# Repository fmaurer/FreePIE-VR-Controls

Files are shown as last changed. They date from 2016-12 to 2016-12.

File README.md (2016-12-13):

# FreePIE-VR-Controls

Emulates HTC Vive Controllers with Arduino's, IMUs, and the Leap Motion sensor. Using the Leap Motion sensor for positional tracking of hands and orientation from an Arduino, HTC Vive controller data is spoofed by using FreePIE to generate Razer Hydra data. To simplify, the Arduino is flashed as a USB joystick and passes orientation data through the 16-bit joystick axis values, along with button presses.

https://youtu.be/kD7rpQKc5ew

Additional info, photos, and videos:
http://flrnmrr.com/2016/11/30/arduino-vive-controller-emulation

Requirements:

- Tracked VR headset (Oculus DK2)
- FreePIE     http://andersmalmgren.github.io/FreePIE/
- Leap Motion sensor, Orion installed     https://api.leapmotion.com/orion
- Steam VR Razer Hydra Driver     http://store.steampowered.com/app/491380/
- Sixsense SDK     http://sixense.com/windowssdkdownload
- "... copy the sixense_fake.dll (located in the root folder of your FreePIE installation) over the sixense.dll in the folder of the application you want use this plugin with. "
- 2 x USB joysticks (i.e. Arduino's simulating joystick HID devices)
- recommended: xbox 360 controller for testing

Arduino:

- Firmware is written for Arduino Pro Micro. Different Arduinos may use different pins
- copy the libraries into your Arduino folder (default is ~/Documents/Arduino/libraries)
- Some can be obtained through the library manager in the Arduino IDE

3D Printer files:

- very early version
- comes as multiple pieces that require to be fused together (e.g. handle and joystick mount)
- requires a lot of modification, I suggest ABS plastic as filament material. Hack your buttons into it, I used arcade buttons

How to Use:

- Run Steam VR
- Open FreePIE, run script
- To calibrate, point the Arduino's IMU/orientation sensor forward and press left-thumbstick down on the 360 controller (change line 163 "if ((xbox360[i].leftThumb) ):" for different key)

Support:

- Sixsense SDK has testing app under "Samples" folder of download
- The script assumes the Arduino-joysticks feeding the orientation data are index 0 and 1. Most problems can be addressed by change these indexes near Line 147: "joyLi" and "joyRi"
- Still having issues? Have you tried Right-click > "Run as Administrator"?
- If all else fails, test if you can make it work with just a 360 controller: http://www.mtbs3d.com/phpbb/viewtopic.php?f=139&t=19270

(More install help: http://www.mtbs3d.com/phpBB/viewtopic.php?f=139&t=19753 )

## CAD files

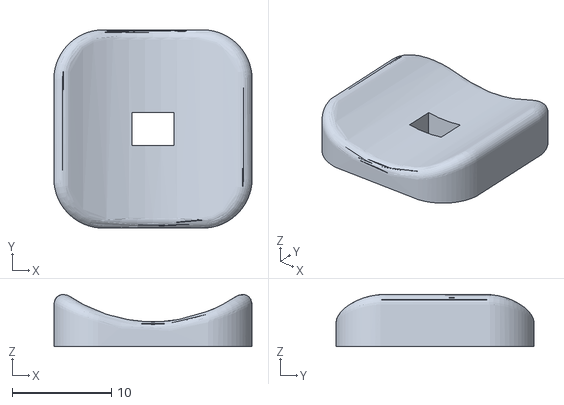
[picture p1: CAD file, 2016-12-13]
3D Printer Files/hand controller joystick shape.stl
20.0 x 20.0 x 5.26

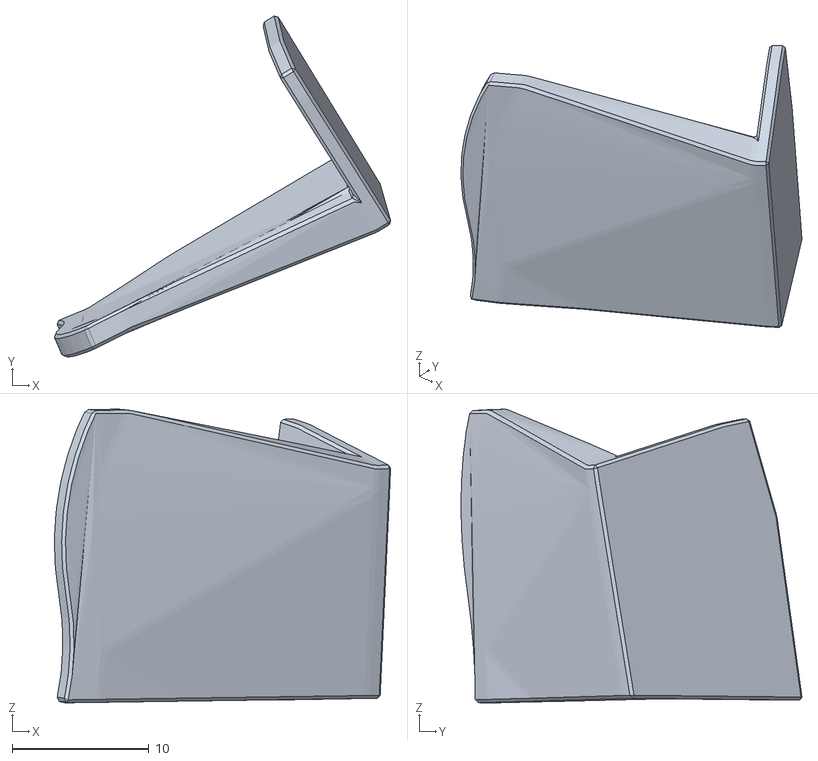
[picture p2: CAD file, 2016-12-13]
3D Printer Files/hand controller 7 lid.stl
24.5 x 24.9 x 21.4

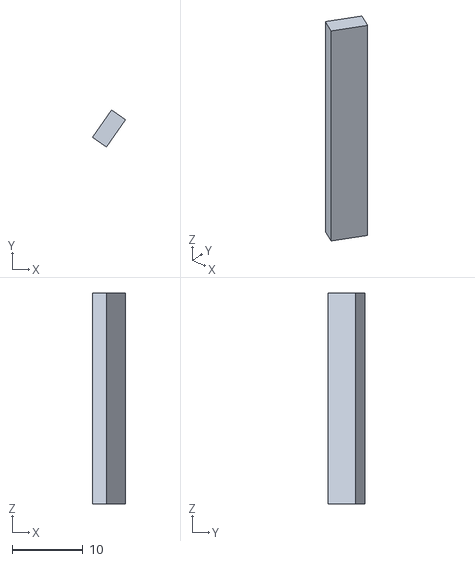
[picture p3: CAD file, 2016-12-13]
3D Printer Files/hand controller 7 joystick thumb centerPin fix 2 x2.stl
4.69 x 5.26 x 29.9

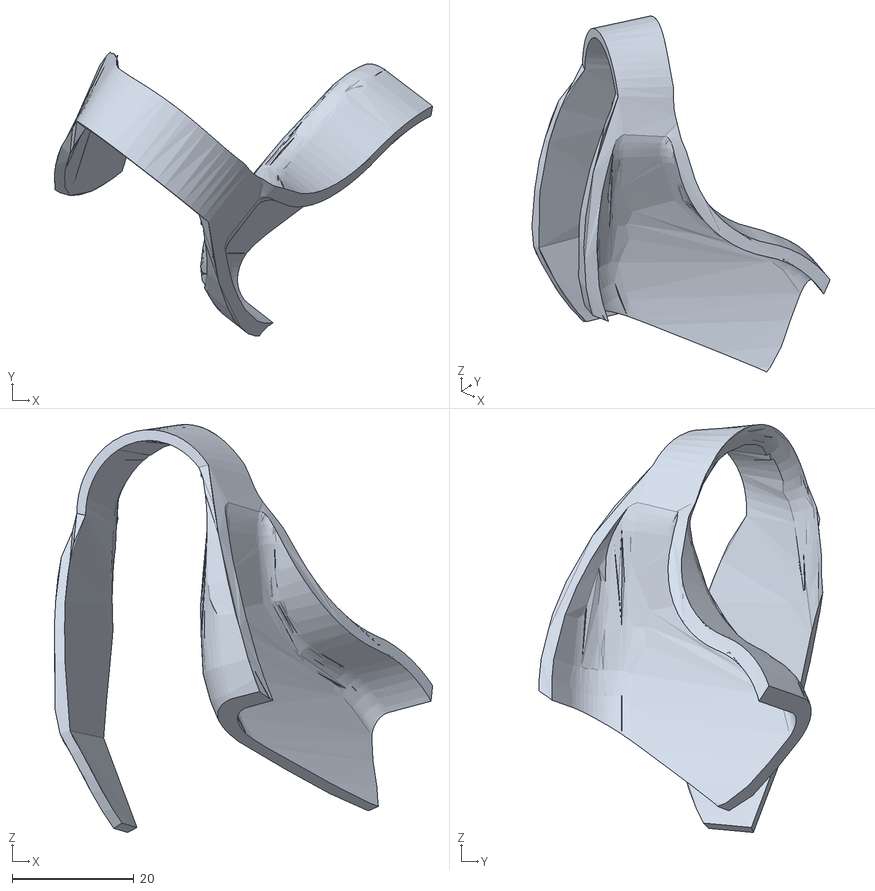
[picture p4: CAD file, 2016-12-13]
3D Printer Files/hand controller og base1.stl
62.1 x 46.5 x 66.9

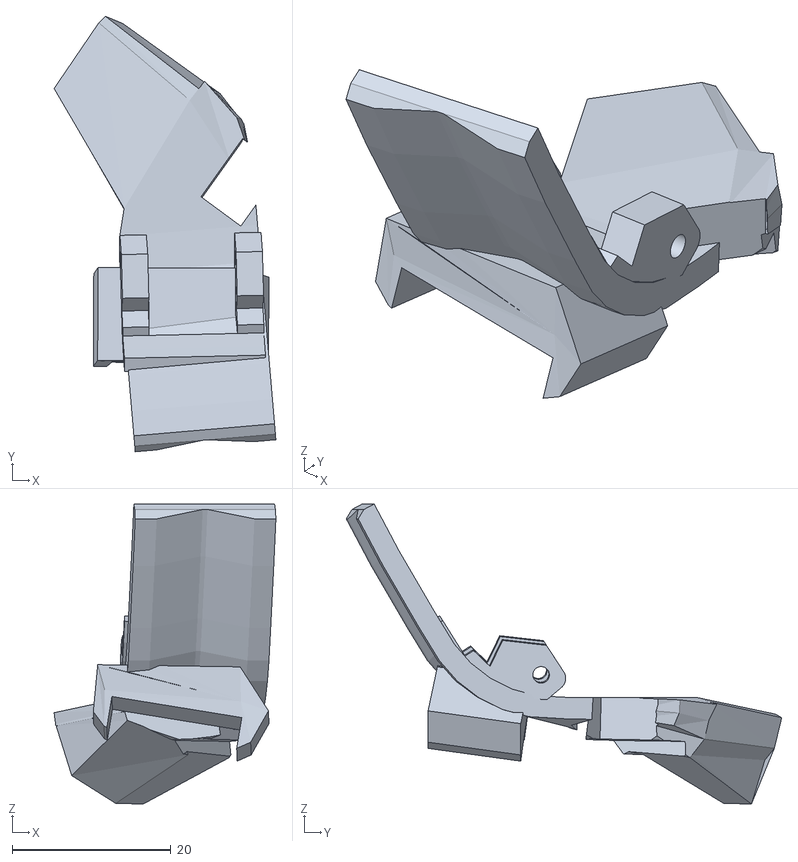
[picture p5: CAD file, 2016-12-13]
3D Printer Files/hand controller og - joystick with button lid 3.stl
28.0 x 54.9 x 37.8

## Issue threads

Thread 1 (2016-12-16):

Possible collaboration?

cnlohr, 2016-12-16:
Would you be interested in working together on this sort of platform?  Specifically, I was wondering if I were to get many sensors working in parallel with an ESP32 if it is something you could port on the backend to the different interfaces on your side and potentially port your interface to my frontend in libsurvive - admittedly it's not quite 100% there yet.

fmaurer, 2016-12-17:
What an honor, I watched all your VODs!

I'm not exactly sure how I fit in but I'm more than happy to help how I can. I'm 95% sure whatever you come up with, we can make it work with FreePIE/Python. I watched your esp32 mouse+keyboard vod;  I'm currently passing quaternions over a joystick axis HID report since I can combine it with buttons. There are some limitations in using FreePIE to emulate the Vive wands, but it's at least convenient to test ideas with.

cnlohr, 2016-12-17:
Oh! I thought you were somehow utilizing the lighthouse data!  Regardless, even if that's not the case, you clearly have figured out ways of feeding data back into the valve subsystems.  One of the things a little later on is where we will be using ESP32s to read current location.   Initially it will only work with our subsystem, but it will certainly be super cool to take that and feed it into the larger vive ecosystem.

cnlohr, 2016-12-17:
Additionally, you have a much firmer grasp on actual controllerifying things than I do.   Maybe we should check back in a few weeks?

fmaurer, 2016-12-17:
Sounds good, let's stay in touch. I'll be following your youtubes

cnlohr, 2016-12-17:
Cool!

Closed 2016-12-17.

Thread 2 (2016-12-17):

license?

slivingston, 2016-12-17:
Can you provide a free, open source license under which the sources are released? Doing so will allow others to more readily contribute.

Might I suggest [the BSD 3-clause license](https://opensource.org/licenses/BSD-3-Clause)? Design or graphics assets like the STL files are sometimes placed under a separate [CreativeCommons](https://creativecommons.org/licenses/by/4.0/) license, e.g., [CC-BY](https://creativecommons.org/licenses/by/4.0/).

ajayyy, 2017-01-15:
I have made a fork and removed the 3d printer files, I hope that is ok with you @fmaurer.

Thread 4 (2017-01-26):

FreePIE doesn't detect Wiimote's Gyroscope Values

meduzo, 2017-01-26:
Sorry wrong place to post this :S

Closed 2017-01-26.

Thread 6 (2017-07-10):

STEAMVR detects the camera instead of the sensors

zivzv, 2017-07-10:
Hey
First of all you have an amazing project!

I'm building a similar project to myself,
and I have a question about your sensor/camera

I have an oculus dk2 clone and the LEAP MOTION
in the In your videos It looks like STEAMVR detects the camera instead of the sensors.
How did you do it?
I am looking for a DIY replacement before I buy on eBay the oculus sensor

ajayyy, 2018-01-05:
(I know your post is old but I'll try to help)

The way this works is by emulating razer hydra controllers, and using the razer hydra steamvr plugin, which makes razer hydras act as steamvr controllers.

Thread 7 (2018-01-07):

Wiimote plus + external magnetometer

Vininess, 2018-01-07:
Hi

I watch your videos and i see you know much about the giros on an android

But i trying to use a wii remote plus to track the yaw, pitch and row and the driver4br to track x,y,z so i noticed that the wiiremote plus, don't have the magnetometer to recalibrate the controllers, it uses the sensor bar, without the sensor bar the controls tends to drift after a hard shake or shorty time

So my question is, is it possible to soldering a magnetometer to get this recalibration or you have any idea what i have to do to solve this issue?

Thanks a lot

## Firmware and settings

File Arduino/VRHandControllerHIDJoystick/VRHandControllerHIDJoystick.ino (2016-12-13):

#include <Bounce2.h>

#include <HID-Project.h>
#include <HID-Settings.h>

#include <Wire.h>
#include <Adafruit_BNO055.h>
#include <Adafruit_Sensor.h>


//========== CONFIGURATION SETTINGS ==========
#define BOUNCE_WAIT 10
#define BOUNCE_COUNT 1
#define ACTIVE_BUTTONS 5

int buttonPins[] = {
  4, //button 1
  5, //button 2
  6, //button 3
  7, //button 4
  8, //button 5
  2, //button 6
  9, //button 7
  7, //button 8
  18, //button 9
  19, //button 1 back panel
  20, //button 2 back panel
  21, //button 3 back panel
  10, //joystick up
  16, //joystick down
  14, //joystick left
  15 // joystick right
};

const int xAxis = 18;         // joystick X axis
const int yAxis = 19;         // joystick Y axis

//========== END CONFIGURATION SETTINGS ==========

// Instantiate button state array
boolean buttonPressed[16];
// Instantiate a Bounce object array to store each debouncer in
Bounce debouncers[16];
//Instantiate a counter array for each button to debounce count timer
int debounceCount[16];

short quatx;
short quaty;
short quatrx;
short quatry;

Adafruit_BNO055 bno = Adafruit_BNO055(55);

#define N  (2)

int RXLED = 17;  // The RX LED has a defined Arduino pin

String inputString = "";         // a string to hold incoming data
boolean stringComplete = false;  // whether the string is complete

bool hasBNO = true;

// parameters for reading the joystick:
int range = 254;               // output range of X or Y movement
int responseDelay = 5;        // response delay of the mouse, in ms
int threshold = range / 4;    // resting threshold
int center = range / 2;       // resting position value

void setup() {
  // put your setup code here, to run once:

inputString.reserve(200);
  Gamepad.begin();

  // Create debounce instances :
   for (int i = 0; i < ACTIVE_BUTTONS; i++) {
     debouncers[i] = Bounce();
     debounceCount[i] = 0;
     pinMode(buttonPins[i],INPUT_PULLUP);
     (debouncers[i]).attach(buttonPins[i]);
     (debouncers[i]).interval(BOUNCE_WAIT);
        delay(100);
     buttonPressed[i] = false;
   }

  //debug:
  //Serial.begin(9600);
  //Serial.setTimeout(10);
  //Serial.println("Orientation Sensor Test"); Serial.println("");


  pinMode(RXLED, OUTPUT);  // Set RX LED as an output
  digitalWrite(RXLED, LOW);


  if(hasBNO){
    /* Initialise the sensor */
    if (!bno.begin())
    {
      /* There was a problem detecting the BNO055 ... check your connections */
      Serial.print("Ooops, no BNO055 detected ... Check your wiring or I2C ADDR!");
      while (1);
    }

    delay(1000);

    bno.setExtCrystalUse(true);
  }

}

void loop() {
  
  // put your main code here, to run repeatedly:
  /* Get a new sensor event */
  //sensors_event_t event;
  //bno.getEvent(&event);

// print the string when a newline arrives or it's been a while:

  if(hasBNO){
      imu::Quaternion quat = bno.getQuat();
        /* Display the quat data ordered: qw, x, y, z*/

        quatx = (short) ( (int) ( quat.x()*32767 ) );
        quaty = (short) ( (int) ( quat.y()*32767 ) );
        quatrx = (short) ( (int) ( quat.z()*32767 ) );
        quatry = (short) ( (int) ( quat.w()*32767 ) );
        
        Gamepad.xAxis(quatx);
        Gamepad.yAxis(quaty);
        Gamepad.rxAxis(quatrx);
        Gamepad.ryAxis(quatry);

        Gamepad.write();
  }

  
  for (int j = 0; j < ACTIVE_BUTTONS; j++) { //iterate over each button (pin)
    
     (debouncers[j]).update(); //check current value
     int value = (debouncers[j]).read();
     
     if ( value == LOW ) { //if button pressed
       
       if(debounceCount[j] == BOUNCE_COUNT && buttonPressed[j] == false) { //the button has been held down long enough and it hasn't been previously registered as pressed
          if(j==0){
            //NKROKeyboard.press(KEY_1);
            Gamepad.press(1);
          }
          if(j==1){
            //NKROKeyboard.press(KEY_2);
            Gamepad.press(2);
          }
          if(j==2){
            //NKROKeyboard.press(KEY_2);
            Gamepad.press(3);
          }
          if(j==3){
            //NKROKeyboard.press(KEY_2);
            Gamepad.press(4);
          }
          if(j==4){
            //NKROKeyboard.press(KEY_2);
            Gamepad.press(5);
          }
          Gamepad.write();
          digitalWrite(RXLED, HIGH);
          //Keyboard.send();
          //Keyboard.press('r');
          //Joystick.pressButton(buttonPresets[j]);
          buttonPressed[j] = true;
          //delay(50);
          //NKROKeyboard.releaseAll();
          //Gamepad.releaseAll();
          //Gamepad.write();
          //delay(50);
        } else {
            if(debounceCount[j] < BOUNCE_COUNT) { 
              debounceCount[j] = debounceCount[j] + 1; //else increment the count
            }
        }
        
      } else { //button is not pressed
        
        if(debounceCount[j] > 0) {
          debounceCount[j] = debounceCount[j] - 1; //keep decreasing count unless 0
        } else {
           //Keyboard.release(char(buttonPresets[j])); //if 0 then release button
           //NKROKeyboard.releaseAll();
           //Joystick.releaseButton(buttonPresets[j]);
           buttonPressed[j] = false;

          if(j==0){
            //NKROKeyboard.press(KEY_1);
            Gamepad.release(1);
          } 
          if(j==1){
            //NKROKeyboard.press(KEY_2);
            Gamepad.release(2);
          }
          if(j==2){
            //NKROKeyboard.press(KEY_2);
            Gamepad.release(3);
          }
          if(j==3){
            //NKROKeyboard.press(KEY_2);
            Gamepad.release(4);
          }
          if(j==4){
            //NKROKeyboard.press(KEY_2);
            Gamepad.release(5);
          }
            Gamepad.write();
            digitalWrite(RXLED, LOW);
        }
        
      }
  }

   // read and scale the two axes:
  int8_t xReading = readAxis(xAxis);
  int8_t yReading = readAxis(yAxis);

  Gamepad.zAxis(map(xReading,-255,255,-255,255));
  Gamepad.rzAxis(map(yReading,-255,255,-255,255));
  Gamepad.write();
 
}

void serialEventRun(void) {
  if (Serial.available()) serialEvent();
}

/*
  SerialEvent occurs whenever a new data comes in the
 hardware serial RX.  This routine is run between each
 time loop() runs, so using delay inside loop can delay
 response.  Multiple bytes of data may be available.
 */
void serialEvent() {
  while (Serial.available()) {
    // get the new byte:
    char inChar = (char)Serial.read();
    //Serial.print(inChar);
    // add it to the inputString:
    inputString += inChar;
    // if the incoming character is a newline, set a flag
    // so the main loop can do something about it:
    //if (inChar == '\r') {
    if(inputString.endsWith("\r") ) {
      stringComplete = true;
      //thrust = inputString.charAt( inputString.length()-2 );
      //digitalWrite(RXLED, HIGH);
    }
  }
}

/*
  reads an axis (0 or 1 for x or y) and scales the
 analog input range to a range from 0 to <range>
 */

int readAxis(int thisAxis) {
  // read the analog input:
  int reading = analogRead(thisAxis);

  // map the reading from the analog input range to the output range:
  reading = map(reading, 0, 1023, 0, range);

  // if the output reading is outside from the
  // rest position threshold,  use it:
  int distance = reading - center;

  if (abs(distance) < threshold) {
    distance = 0;
  }

  // return the distance for this axis:
  return distance;
}

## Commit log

2016-12-13 Initial release
    Includes Arduino firmware and library dependancies, FreePIE script, and
    install instructions
2016-12-13 Better documentation, added 3D printer files
    [hand controller 7 joystick thumb centerPin fix 2 x2.stl, hand controller 7 lid.stl, hand controller joystick shape.stl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]
